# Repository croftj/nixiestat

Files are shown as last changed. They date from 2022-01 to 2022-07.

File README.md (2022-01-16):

# NixieStat Home Thermostat

NxieStat is thermostat for the home with a nixie tube display supporting
remote sensors.

All comminications to the thermostat is over wifi using the Mosquitto MQTT
message bus. The messages are in the form of json strings. 

This prject started out as an AVR based thermostat. You will see vestiges of
that in source tree. The latest code and hardware is under the **esp32**
folder. The hope is that there will be a web ui running on a Raspberry PI. The
start of this code is in the **webui** folder. It is very early code that is
mostly to prove certain components/SDKs such as **QT** & **WT** can actually be 
compiled together on the Rasberry PI.

## Hardware

### Devboard
This is currently the most tested of the two ESP32 boards. It handle an
ESP32-S2 processor. It also has a three pin connector for easily attaching a
DS18S20 temperature sensor to it. Its  primary purpose is for the temperature
sensors.

### Devboard2
This board is similar to *DevBoard* except that it is laid out for the
ESP32-WROVER-IE processor. This board has not been tested yet. It will
hopefully be the processor for use as the thermostat itself and be able to be
upgraded *over the air*

### CPU Board
This board has the relays for the furnace as wll as the interface chips for the
keyboard an the display board. It can use either *Devboard* or *Devboard2* for
it's processor board.

## Nixie Display
This board has the High voltage supply as well as the nixie tubes and neon
bulbs for the display.

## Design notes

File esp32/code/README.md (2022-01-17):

# NixieStat Thermostat Code

This code is the main source code for the NixieStat Thermostat. It is
structured to be built using the Espressif idf.py tool.

This code requires code from the github project croftj/esp_components. This 
repository should be cloned and a symbolic link named cpp_components needs to
be created in the main folder of this code pointing to the folder with code from
esp_components.

This code can be built and loaded onto the ESP32 devboard for the thermostat
using the command

   *idf.py -p /dev/ttyUSBXX build flash monitor*

Assuming that the esp32 sdk environment was previous installed and configured.

Once the unit was flashed, it will attempt to connect to wifi and the message
bus. This cannot happen until the menus are brought up by pressing <Enter> 
and setting the wifi and the MQTT parameters are configured. The menus can be traversed
using single letters. This initialization  is a bit
cumbersome because of the debug messaging, but doable. Once the parameters are
set, reset the board and it should then connect.

A value can be set by using it's name or the single letter followed without
spaces an '=' then the value. As an example *b=72<Enter>*.

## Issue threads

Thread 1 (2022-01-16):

Provide feedback for invalid configuration requests

croftj, 2022-01-16:
Currently, is a configuration is sent with an error in the value for the json format, there is no feedback on the response topic

Closed 2022-02-04.

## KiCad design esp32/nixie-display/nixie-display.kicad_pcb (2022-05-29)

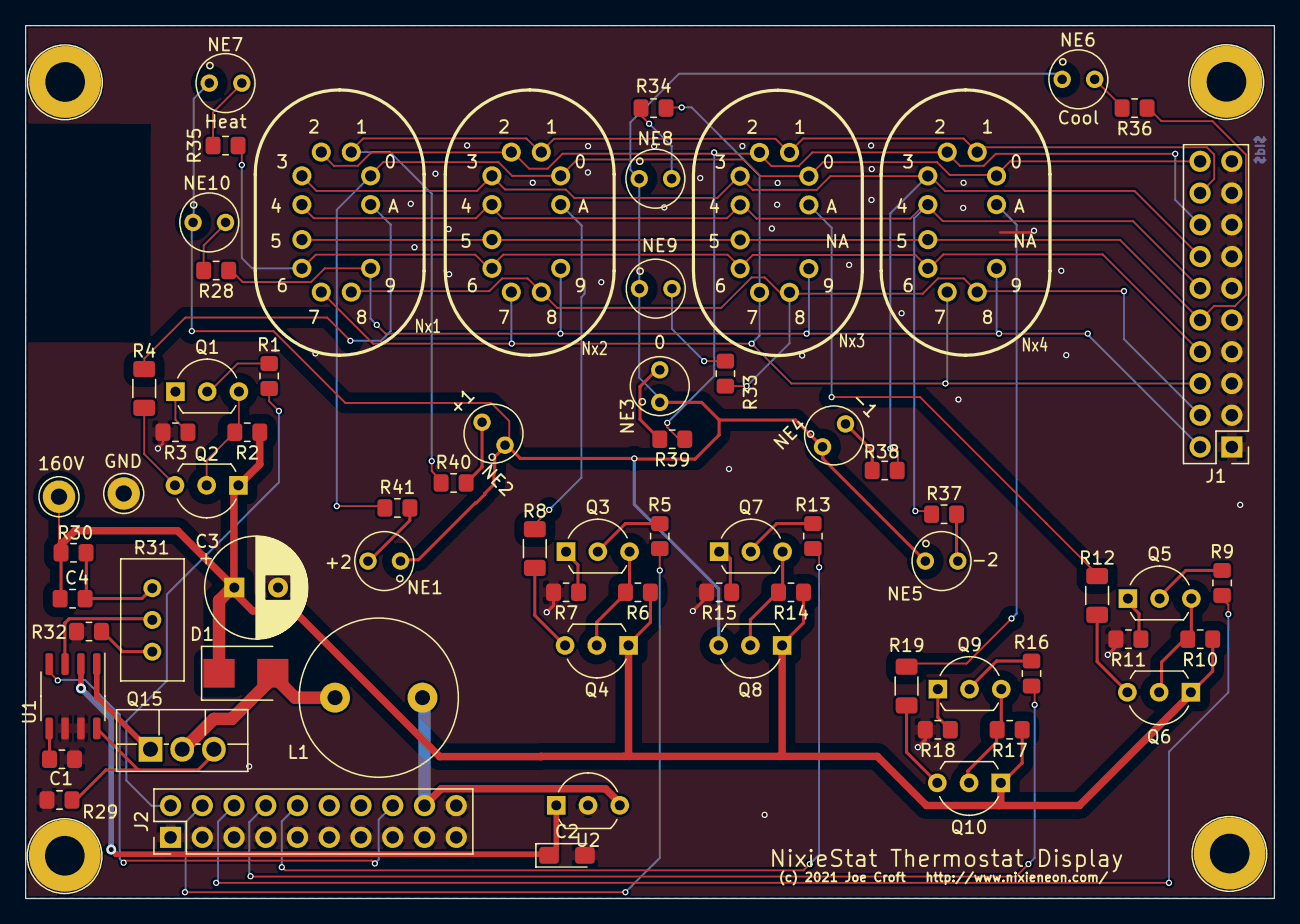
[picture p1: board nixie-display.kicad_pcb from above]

Board: 2 copper layers, 99.9 x 69.8 mm, 74 parts (0 on the bottom side), 61 nets.

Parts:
C1: 1nf; R_0805_2012Metric_Pad1.20x1.40mm_HandSolder
C2: 10uf; CP_EIA-3216-18_Kemet-A_Pad1.58x1.35mm_HandSolder
C3: 4.7uf; CP_Radial_D8.0mm_P3.50mm
C4: 2.2nf; R_0805_2012Metric_Pad1.20x1.40mm_HandSolder
D1: D_Schottky; D_SMB
J1, J2: Conn_02x10_Odd_Even; PinHeader_2x10_P2.54mm_Vertical
L1: 150uh; L_Radial_D12.5mm_P7.00mm_Fastron_09HCP
NE1: +2; NE2
NE2: +1; NE2
NE3: 0; NE2
NE4: -1; NE2
NE5: -2; NE2
NE6: Cool; NE2
NE7: Heat; NE2
NE8, NE9, NE10: Lamp_Neon; NE2
Nx1, Nx2, Nx3, Nx4: in17
Q1, Q3, Q5, Q7, Q9: MPSA42; TO-92L_Inline_Wide
Q2, Q4, Q6, Q8, Q10: MPSA92; TO-92L_Inline_Wide
Q15: IRLS640; TO-220F-3_Vertical
R1, R3, R5, R7, R9, R11, R13, R15, R16, R18: 3.3K; R_0805_2012Metric_Pad1.20x1.40mm_HandSolder
R2, R6, R10, R14, R17, R28, R33, R34, R35, R36, R37, R38, R39, R40, R41: 100K; R_0805_2012Metric_Pad1.20x1.40mm_HandSolder
R4, R8, R12, R19: 22K; R_1206_3216Metric_Pad1.30x1.75mm_HandSolder
R29: .1; R_0805_2012Metric_Pad1.20x1.40mm_HandSolder
R30: 1M; R_0805_2012Metric_Pad1.20x1.40mm_HandSolder
R31: 20K; Potentiometer_Bourns_3296W_Vertical
R32: 1.2K; R_0805_2012Metric_Pad1.20x1.40mm_HandSolder
SH1, SH2, SH3, SH4: ScrewHole; 4-40-Screw
TP1: 160V; Pin_D1.3mm_L11.0mm
TP2: GND; Pin_D1.3mm_L11.0mm
U1: MAX1771; SO-8_3.9x4.9mm_P1.27mm
U2: L78L05_TO92; TO-92_Inline_Wide

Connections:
160V: C3.1, C4.1, D1.1, Q2.1, Q4.1, Q6.1, Q8.1, Q10.1, R2.1, R6.1, R10.1, R14.1, R17.1, R30.1, TP1.1
+5V: C2.1, U1.2, U2.1
/seg0: J1.20, Nx1.0, Nx2.0, Nx3.0, Nx4.0, R41.1
/seg1: J1.18, Nx1.1, Nx2.1, Nx3.1, Nx4.1, R40.1
/seg2: J1.16, Nx1.2, Nx2.2, Nx3.2, Nx4.2, R39.1
/seg3: J1.14, Nx1.3, Nx2.3, Nx3.3, Nx4.3, R38.1
/seg4: J1.12, Nx1.4, Nx2.4, Nx3.4, Nx4.4, R37.1
/seg5: J1.10, Nx1.5, Nx2.5, Nx3.5, Nx4.5, R36.1
/seg6: J1.8, Nx1.6, Nx2.6, Nx3.6, Nx4.6, R35.1
/seg7: J1.6, Nx1.7, Nx2.7, Nx3.7, Nx4.7, R34.1
/seg8: J1.4, Nx1.8, Nx2.8, Nx3.8, Nx4.8, R33.1
/seg9: J1.2, Nx1.9, Nx2.9, Nx3.9, Nx4.9, R28.1
GNDREF: C1.2, C2.2, C3.2, J1.1, J1.3, J1.5, J1.7, J1.9, J1.11, J1.13, J1.15, J1.17, J1.19, J2.1, J2.3, J2.5, J2.7, J2.9, J2.11, J2.13, J2.15, J2.17, J2.19, J2.20, R3.2, R7.2, R11.2, R15.2, R18.2, R29.2, R32.2, SH1.1, SH2.1, SH3.1, SH4.1, TP2.1, U1.6, U1.7, U2.2
HV_DISABLE: J2.16, U1.4
unnamed: C1.1, U1.5
unnamed: C4.2, R30.2, R31.1
unnamed: D1.2, L1.2, Q15.2
unnamed: NE1.2, R41.2
unnamed: NE2.2, R40.2
unnamed: NE3.2, R39.2
unnamed: NE4.2, R38.2
unnamed: NE5.2, R37.2
unnamed: NE6.2, R36.2
unnamed: NE7.2, R35.2
unnamed: NE8.2, R34.2
unnamed: NE9.2, R33.2
unnamed: NE10.2, R28.2
unnamed: Q1.1, R3.1
unnamed: Q1.2, R1.1
unnamed: Q1.3, Q2.2, R2.2
unnamed: Q2.3, R4.2
unnamed: Q3.1, R7.1
unnamed: Q3.2, R5.1
unnamed: Q3.3, Q4.2, R6.2
unnamed: Q4.3, R8.2
unnamed: Q5.1, R11.1
unnamed: Q5.2, R9.1
unnamed: Q5.3, Q6.2, R10.2
unnamed: Q6.3, R12.2
unnamed: Q7.1, R15.1
unnamed: Q7.2, R13.1
unnamed: Q7.3, Q8.2, R14.2
unnamed: Q9.1, R18.1
unnamed: Q9.2, R16.1
unnamed: Q9.3, Q10.2, R17.2
unnamed: Q10.3, R19.2
unnamed: Q15.1, U1.1
unnamed: Q15.3, R29.1, U1.8
unnamed: R31.2, U1.3
unnamed: R31.3, R32.1
VCC: J2.18, L1.1, U2.3
dig0: Nx1.A, R4.1
dig1: Nx2.A, R8.1
dig2: Nx3.A, R12.1
dig3: Nx4.A, R19.1
dig4: NE1.1, NE2.1, NE3.1, NE4.1, NE5.1, NE6.1, NE7.1, NE8.1, NE9.1, NE10.1, Q8.3
idig0: J2.2, R1.2
idig1: J2.4, R5.2
idig2: J2.6, R9.2
idig3: J2.8, R16.2
idig4: J2.10, R13.2

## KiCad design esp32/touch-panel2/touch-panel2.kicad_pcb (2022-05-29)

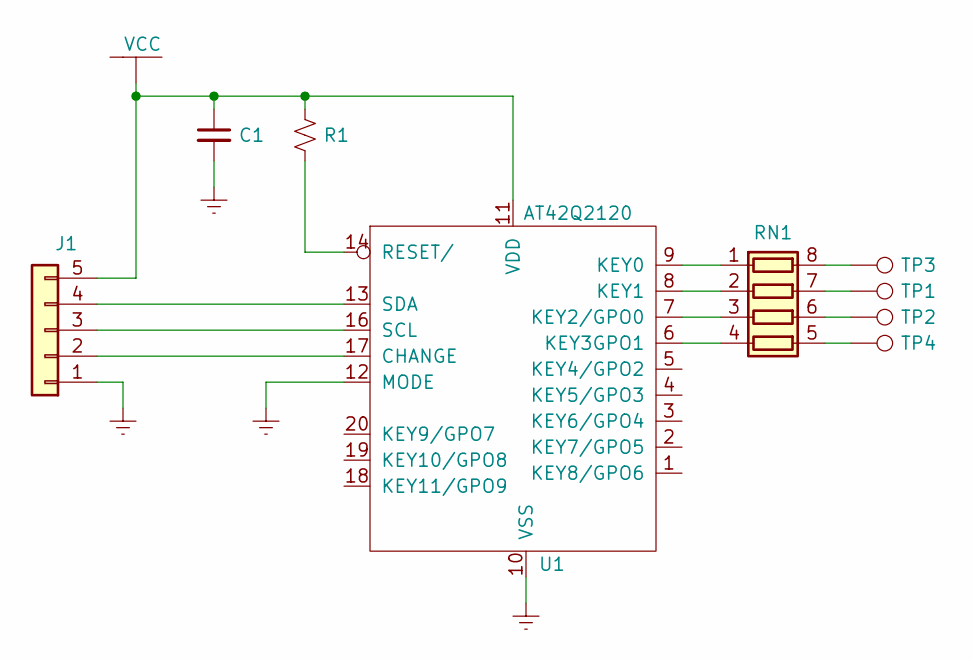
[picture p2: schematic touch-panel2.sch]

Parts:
C1: C_Small; C_0805_2012Metric_Pad1.18x1.45mm_HandSolder
J1: Conn_01x05; PinHeader_1x05_P2.54mm_Vertical
R1: R_Small_US; R_0805_2012Metric_Pad1.20x1.40mm_HandSolder
RN1: R_Pack04; R_Array_Convex_4x0603
TP1, TP2, TP3, TP4: TestPoint; Touch_Pad_Small
U1: AT42Q2120; TSSOP-20_4.4x6.5mm_P0.65mm
V1: VCC

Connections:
GNDREF: C1.2, J1.1, U1.10 (VSS), U1.12 (MODE)
unnamed: J1.2, U1.17 (CHANGE)
unnamed: J1.3, U1.16 (SCL)
unnamed: J1.4, U1.13 (SDA)
unnamed: R1.2, U1.14 (RESET/)
unnamed: RN1.1 (R1.1), U1.9 (KEY0)
unnamed: RN1.2 (R2.1), U1.8 (KEY1)
unnamed: RN1.3 (R3.1), U1.7 (KEY2/GPO0)
unnamed: RN1.4 (R4.1), U1.6 (KEY3GPO1)
unnamed: RN1.5 (R4.2), TP4.1
unnamed: RN1.6 (R3.2), TP2.1
unnamed: RN1.7 (R2.2), TP1.1
unnamed: RN1.8 (R1.2), TP3.1
VCC: C1.1, J1.5, R1.1, U1.11 (VDD), V1.1

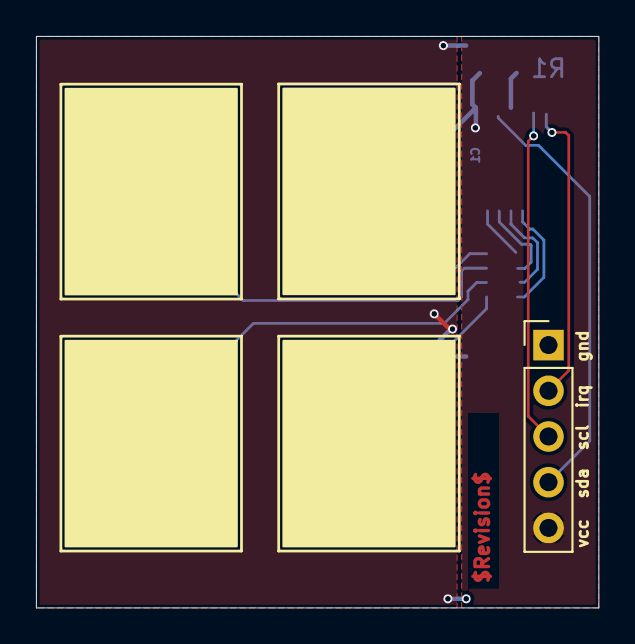
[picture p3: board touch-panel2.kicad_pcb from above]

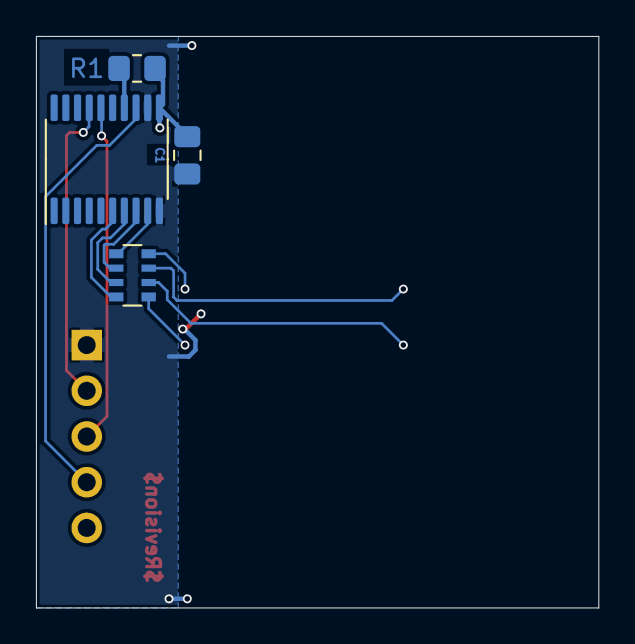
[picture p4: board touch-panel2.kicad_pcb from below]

Board: 2 copper layers, 31.2 x 31.7 mm, 9 parts (4 on the bottom side), 14 nets.

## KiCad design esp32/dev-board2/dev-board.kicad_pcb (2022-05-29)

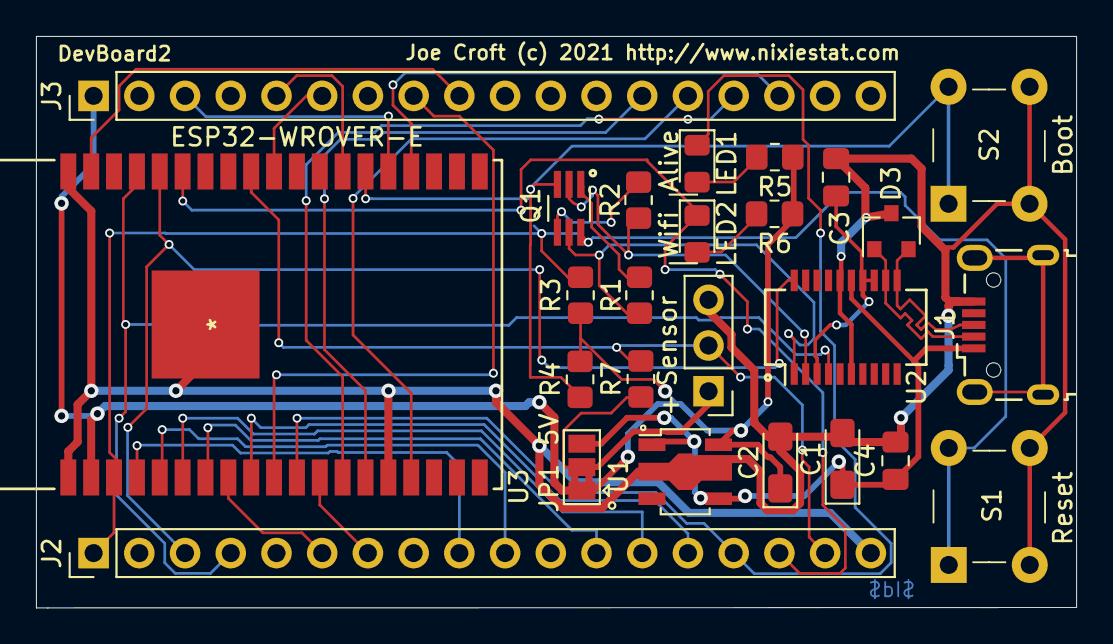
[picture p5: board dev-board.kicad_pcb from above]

Board: 2 copper layers, 57.8 x 31.8 mm, 25 parts (0 on the bottom side), 36 nets.

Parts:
C1, C2: 10uf; CP_EIA-3216-18_Kemet-A_Pad1.58x1.35mm_HandSolder
C3, C4: .1uf; C_0805_2012Metric_Pad1.18x1.45mm_HandSolder
D3: STS232; SOT-23
J1: USB_B_Micro; USB_Micro-B_Wuerth_629105150521
J2, J3: Conn_01x18_Male; PinHeader_1x18_P2.54mm_Vertical
J4: Conn_01x03_Male; PinHeader_1x03_P2.54mm_Vertical
JP1: Jumper_3_Bridged12; SolderJumper-3_P1.3mm_Bridged2Bar12_Pad1.0x1.5mm
LED1, LED2: LED; LED_0805_2012Metric_Pad1.15x1.40mm_HandSolder
Q1: MTB3904-2; SOT-363_SC-70-6_Handsoldering
R1, R2, R3, R4: 10K; R_0805_2012Metric_Pad1.20x1.40mm_HandSolder
R5, R6: 75; R_0805_2012Metric_Pad1.20x1.40mm_HandSolder
R7: 2.3K; R_0805_2012Metric_Pad1.20x1.40mm_HandSolder
S1, S2: B3F-1052; Switch_Tactile_THT_B3F-1xxx
U1: AP7361C-33Y5-13; SOT-89-5
U2: FT231XS; SSOP-20_3.9x8.7mm_P0.635mm
U3: ESP32-WROVER-E; ESP32-WROVER-EM213EH2864PH3Q0

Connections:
+3.3V: C2.1, J3.1, JP1.1, R3.2, R4.2, R5.1, R6.1, U1.5, U3.2
+5V: C1.1, C4.1, J1.1, JP1.3, U1.1, U1.4, U2.15
/USB_N: D3.1, J1.2, U2.12
/USB_P: D3.2, J1.3, U2.11
GNDREF: C1.2, C2.2, C3.2, C4.2, D3.3, J1.5, J2.18, J4.3, S1.3, S1.4, S2.3, S2.4, U1.2, U2.6, U2.16, U3.1, U3.15, U3.38, U3.39
IO-00: Q1.3, R4.1, S2.1, S2.2, U3.25
IO-02: J3.3, U3.24
IO-04: J3.5, U3.26
IO-05: J3.6, U3.29
IO-12: J3.13, U3.14
IO-13: J3.14, U3.16
IO-14: J3.15, U3.13
IO-15: J3.16, U3.23
IO-18: J2.17, J4.2, R7.2, U3.30
IO-21: J2.16, LED2.1, U3.33
IO-23: J3.9, U3.37
IO-25: J3.8, U3.10
IO-26: J2.15, LED1.1, U3.11
IO-27: J2.7, U3.12
IO-32: J2.6, U3.8
IO-33: J2.14, U3.9
IO-34: J2.13, U3.6
IO-35: J2.12, U3.7
unnamed: C3.1, U2.3, U2.13, U2.14
unnamed: J4.1, JP1.2, R7.1
unnamed: LED1.2, R5.2
unnamed: LED2.2, R6.2
unnamed: Q1.1, R1.2
unnamed: Q1.2, R2.1, U2.2
unnamed: Q1.4, R2.2
unnamed: Q1.5, R1.1, U2.1
RESET: J2.1, Q1.6, R3.1, S1.1, S1.2, U3.3
RXD0: J2.3, U2.20, U3.34
SENSOR_VN: J2.10, U3.5
SENSOR_VP: J2.9, U3.4
TXD0: J2.4, U2.4, U3.35

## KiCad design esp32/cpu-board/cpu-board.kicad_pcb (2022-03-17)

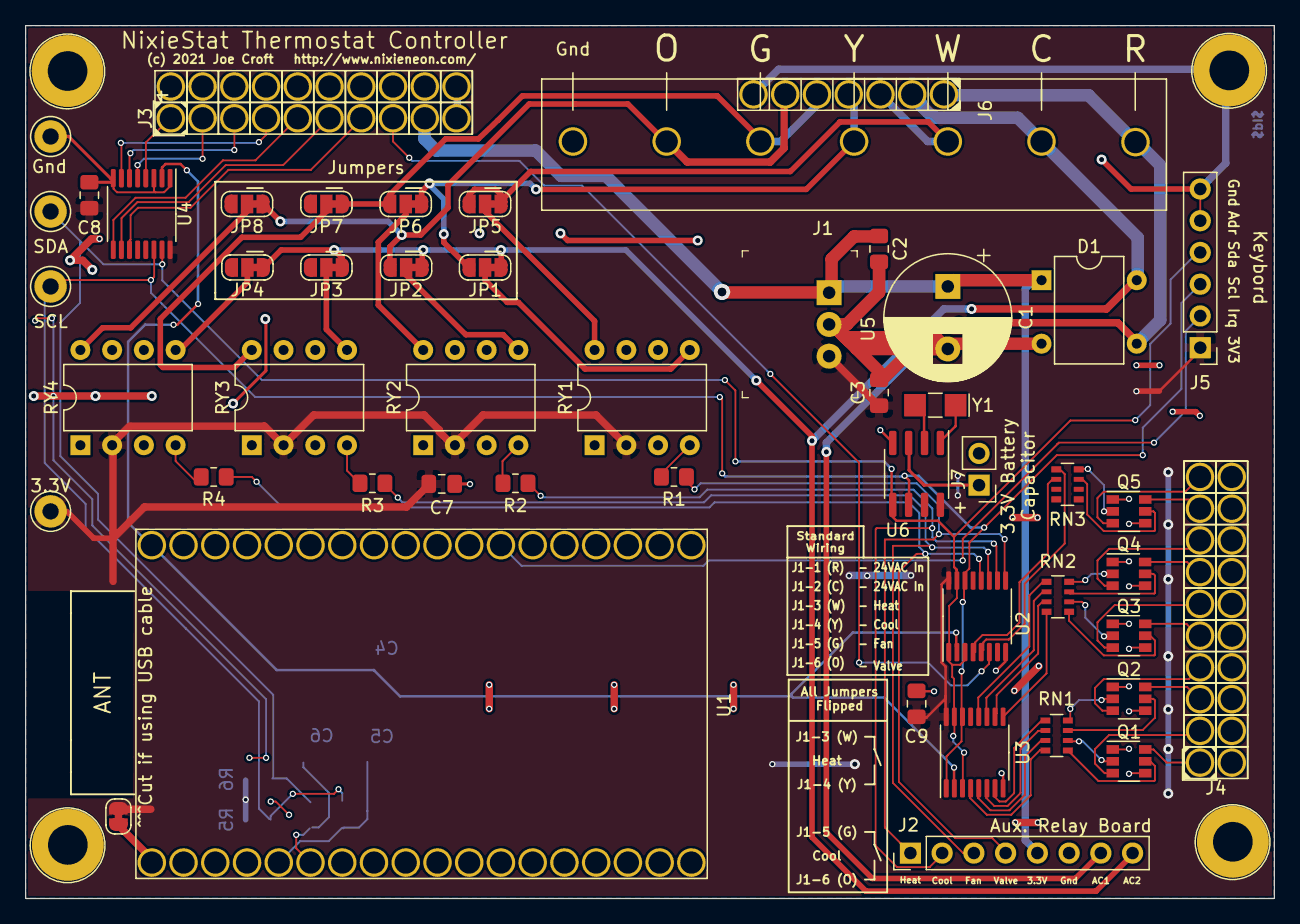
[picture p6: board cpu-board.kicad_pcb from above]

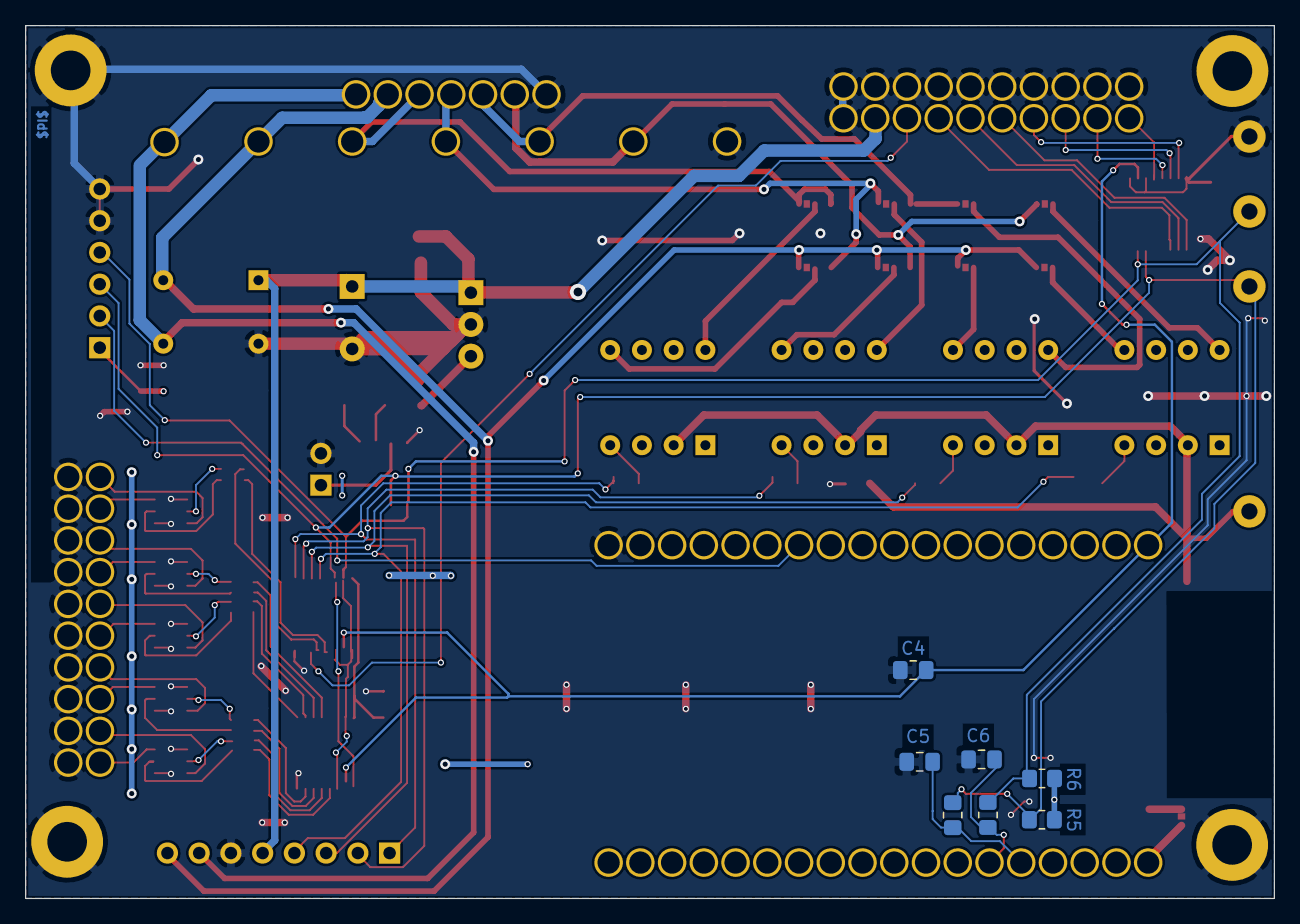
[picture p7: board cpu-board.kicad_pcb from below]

Board: 2 copper layers, 99.9 x 69.8 mm, 61 parts (7 on the bottom side), 73 nets.

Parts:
C1: 100uf 35V; CP_Radial_D10.0mm_P5.00mm
C2, C3: 10uf 35V; C_0805_2012Metric_Pad1.18x1.45mm_HandSolder
C4, C5, C6, C7, C8, C9: .1uf; C_0805_2012Metric_Pad1.18x1.45mm_HandSolder
D1: DF01M; Diode_Bridge_DIP-4_W7.62mm_P5.08mm
J1: Conn_01x07; conn-phx-1703090
J2: Conn_01x08; PinHeader_1x08_P2.54mm_Vertical
J3: Conn_02x10_Odd_Even; pcb_jack-2x10
J4: Conn_02x10_Odd_Even; pcb_jack-2x10-mirror
J5: Conn_01x06; PinHeader_1x06_P2.54mm_Vertical
J6: Conn_01x07; Mill-Max-295x7
J7: Battery; PinHeader_1x02_P2.54mm_Vertical
JP1, JP2, JP3, JP4, JP5, JP6, JP7, JP8: SolderJumper_3_Bridged12; SolderJumper-3_P1.3mm_Bridged12_RoundedPad1.0x1.5mm_NumberL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
JP9: Jumper_2_Bridged; SolderJumper-2_P1.3mm_Bridged_RoundedPad1.0x1.5mm
Q1, Q2, Q3, Q4, Q5: PMBTA42DS,125; SuperSOT-6
R1, R2, R3, R4: R_US; R_0805_2012Metric_Pad1.20x1.40mm_HandSolder
R5, R6: 100K; R_0805_2012Metric_Pad1.20x1.40mm_HandSolder
R7, R8: 0 Ohm; R_0805_2012Metric_Pad1.20x1.40mm_HandSolder
RN1, RN2, RN3: R_Pack04; R_Array_Convex_4x0603
RY1, RY2, RY3, RY4: AQH3213; DIP-8_W7.62mm
SH1, SH2, SH3, SH4: ScrewHole; 4-40-Screw
TP1: Gnd; Pin_D1.3mm_L11.0mm
TP2: SCL; Pin_D1.3mm_L11.0mm
TP3: SDA; Pin_D1.3mm_L11.0mm
TP4: 3.3V; Pin_D1.3mm_L11.0mm
U1: ESP32-DevBoard2; ESP32-DevKit-pcb-recepticals
U2, U3, U4: MAX7320; TSSOP-16_4.4x5mm_P0.65mm
U5: V7803-1000; 3-SIP_Module_V7805-1000
U6: PT7C4339; SOIC-8_3.9x4.9mm_P1.27mm
Y1: 32.788Khz; Crystal_SMD_G8-2Pin_3.2x1.5mm_HandSoldering

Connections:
+3.3V: C3.1, C7.1, C8.1, C9.1, J5.1, JP9.1, R5.1, R6.1, RY1.2, RY2.2, RY3.2, RY4.2, TP4.1, U2.16, U3.16, U4.16, U5.3, U6.8
AC1: D1.3, J1.1, J2.7, J6.1
AC2: D1.4, J1.2, J2.8, J6.2, JP1.1, JP2.1, JP3.1, JP4.1
COOL: J2.2, R2.2, U2.10
FAN: J2.3, R3.2, U2.11
GNDREF: C1.2, C2.2, C3.2, C4.2, C5.2, C6.2, C7.2, C8.2, C9.2, D1.2, J1.7, J2.6, J3.2, J3.4, J3.6, J3.8, J3.10, J3.12, J3.14, J3.16, J3.18, J3.19, J3.20, J4.2, J4.4, J4.6, J4.8, J4.10, J4.12, J4.14, J4.16, J4.18, J4.20, J5.5, J5.6, J6.7, J7.2, Q1.1, Q1.4, Q2.1, Q2.4, Q3.1, Q3.4, Q4.1, Q4.4, Q5.1, Q5.4, SH1.1, SH2.1, SH3.1, SH4.1, TP1.1, U1.19, U2.8, U3.8, U4.1, U4.3, U4.8, U5.2, U6.4
HEAT: J2.1, R1.2, U2.9
I2C_SCL: J5.3, R5.2, R7.1, TP2.1, U2.14, U3.1, U3.14, U4.14, U6.6
I2C_SDA: J5.4, R6.2, R8.1, TP3.1, U2.1, U2.3, U2.15, U3.3, U3.15, U4.15, U6.5
KEY_IRQ: J5.2, U1.25
unnamed: C5.1, R7.2, U1.5
unnamed: C6.1, R8.2, U1.6
unnamed: J1.3, J6.3, JP5.1, JP5.3
unnamed: J1.4, J6.4, JP1.3, JP6.1
unnamed: J1.5, J6.5, JP6.3, JP7.1
unnamed: J1.6, J6.6, JP2.3, JP8.1
unnamed: J3.1, U4.4
unnamed: J3.3, U4.5
unnamed: J3.5, U4.6
unnamed: J3.7, U4.7
unnamed: J3.9, U4.9
unnamed: J3.11, U4.10
unnamed: J3.13, U4.11
unnamed: J7.1, U6.3
unnamed: JP1.2, RY1.5
unnamed: JP2.2, RY2.5
unnamed: JP3.2, RY3.5
unnamed: JP4.2, RY4.5
unnamed: JP5.2, RY1.8
unnamed: JP6.2, RY2.8
unnamed: JP7.2, RY3.8
unnamed: JP8.2, RY4.8
unnamed: JP9.2, U1.1
unnamed: R1.1, RY1.4
unnamed: R2.1, RY2.4
unnamed: R3.1, RY3.4
unnamed: R4.1, RY4.4
unnamed: RN1.5, U3.7
unnamed: RN1.6, U3.6
unnamed: RN1.7, U3.5
unnamed: RN1.8, U3.4
unnamed: RN2.5, U3.12
unnamed: RN2.6, U3.11
unnamed: RN2.7, U3.10
unnamed: RN2.8, U3.9
unnamed: RN3.5, U2.5
unnamed: RN3.6, U2.4
unnamed: U6.1, Y1.1
unnamed: U6.2, Y1.2
RESET: C4.1, U1.36, U2.2, U3.2, U4.2
SEG1: Q1.5, RN1.1
SEG2: Q1.2, RN1.2
SEG3: Q2.5, RN1.3
SEG4: Q2.2, RN1.4
SEG5: Q3.5, RN2.1
SEG6: Q3.2, RN2.2
SEG7: Q4.5, RN2.3
SEG8: Q4.2, RN2.4
SEG9: Q5.5, RN3.3
SEG10: Q5.2, RN3.4
SEG_D_1: J4.1, Q1.6
SEG_D_2: J4.3, Q1.3
SEG_D_3: J4.5, Q2.6
SEG_D_4: J4.7, Q2.3
SEG_D_5: J4.9, Q3.6
SEG_D_6: J4.11, Q3.3
SEG_D_7: J4.13, Q4.6
SEG_D_8: J4.15, Q4.3
SEG_D_9: J4.17, Q5.6
SEG_D_10: J4.19, Q5.3
VALVE: J2.4, R4.2, U2.12
VCC: C1.1, C2.1, D1.1, J2.5, J3.17, U5.1
~HV_EN~: J3.15, U2.6

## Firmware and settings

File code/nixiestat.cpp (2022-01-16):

//#define  MINIMAL
//#define  NO_EXEC
//#define  NO_LOG
//#define  NO_MENU_EXEC
//#define  DISPLAY_OFF
// #define  DBG
#define  POLLING  1
#define REGCHANNEL

# include <avr/pgmspace.h>
# include <ctype.h>
# include <math.h>
# include <stdio.h>
# include <stdlib.h>

# include "EEPROM.h"
# include "IOPort.h"

# include "datetime.h"
# include "esquare.h"
# include "menu.h"

#ifndef MINIMAL 
# include "display.h"
# include "PID.h"
# include "SystemLogger.h"
# include "TempCycle.h"
# include "TempSensors.h"
# include "thermostat.h"
# include "WProgram.h"
# include "Wire.h"
# include "ds1307.h"
# include "mpr121.h"
# include "switches.h"
# include "ui.h"
#endif

#define  LOG_SIZE                (15 * 1024)
//#define  LOG_SIZE                (100)
#define  READ_TEMPERATURE_TIME   15
#define  READ_SENSOR_TIME        2
#define  DISP_TEMPERATURE_TIME   10
#define  LOG_TEMPERATURE_TIME    (30 * 60)
//#define  LOG_TEMPERATURE_TIME    (30)
#define  RESERVED_STACK          8192

enum
{
   TIME_LAPSE_MASK  = 0xf000,
   TIME_LAPSE_SHIFT = 12,
   CHANNEL_MASK     = 0x0c00,
   CHANNEL_SHIFT    = 10,
   TEMPERATURE_MASK = 0x03ff,
   TEMPERATURE_SIGN = 0x0200,
   LOG_LENGTH       = 12 * 1024,
   TEMP_OFFSET      = 40
};

#ifdef DBG
uint8_t dbg = 4;
#else
uint8_t dbg = 0;
#endif

#ifndef MINIMAL 
#ifndef NO_LOG
SystemLogger syslog;
#endif

TempSensors sensors;
PID pid(5, 2, 10);

MPR121 mpr121;
#endif

bool tempIsReady = 0;
uint8_t tempCounter = 12;

char p_buf[128];
char ibuf[32];
bool needPrompt = 0;
bool *pid_debug = NULL;

MenuEntry *main_menu;

const char invalidEntry_str[] PROGMEM = "\nInvalid Entry!";

# ifdef REGCHANNEL
#ifndef NO_LOG
const char OUTSIDE_SENSOR_AVG_LOG[] PROGMEM  = "OutAvg";
const char OUTSIDE_SENSOR_MIN_LOG[] PROGMEM  = "OutMin";
const char OUTSIDE_SENSOR_MAX_LOG[] PROGMEM  = "OutMax";

const char INSIDE_SENSOR_AVG_LOG[] PROGMEM   = "InAvg";
const char INSIDE_SENSOR_MIN_LOG[] PROGMEM   = "InMin";
const char INSIDE_SENSOR_MAX_LOG[] PROGMEM   = "InMax";

const char CYCLE_SENSOR_TGT_LOG[] PROGMEM    = "CycTgt";
const char CYCLE_SENSOR_AVG_LOG[] PROGMEM    = "CycAvg";
const char CYCLE_SENSOR_MIN_LOG[] PROGMEM    = "CycMin";
const char CYCLE_SENSOR_MAX_LOG[] PROGMEM    = "CycMax";
const char CYCLE_STATE_LOG[]      PROGMEM    = "CycState";

const char TARGET_TEMP_LOG[] PROGMEM         = "TgtTemp";
const char PID_ITERM_LOG[] PROGMEM           = "PIDITerm";
# endif
# endif
/**********************************************************************/
/*   Menu Strings                                                     */
/**********************************************************************/
const char MENU_MAINMENU_STR[] PROGMEM = "Main Menu";

const char MENU_MM11_STR[] PROGMEM = "Cycle State";
const char MENU_MM10_STR[] PROGMEM = "Cycle Temp.";
const char MENU_MM9_STR[]  PROGMEM = "Outside Temp.";
const char MENU_MM8_STR[]  PROGMEM = "Inside Temp.";
const char MENU_MM7_STR[]  PROGMEM = "Dump full Log";
const char MENU_MM6_STR[]  PROGMEM = "Dump Log";
const char MENU_MM5_STR[]  PROGMEM = "Save Settings";
const char MENU_MM4_STR[]  PROGMEM = "Date";
const char MENU_MM3_STR[]  PROGMEM = "Time";
const char MENU_MM2_STR[]  PROGMEM = "Mode";
const char MENU_MM1_STR[]  PROGMEM = "Set Temperature";

const char MENU_SYSMENU_STR[]    PROGMEM = "System";
const char MENU_SY7_STR[]        PROGMEM = "PID Debug";
const char MENU_SY6_STR[]        PROGMEM = "Reset Count";
const char MENU_SY5_STR[]        PROGMEM = "Clear Log";
const char MENU_SY4_STR[]        PROGMEM = "Show Esquare";
const char MENU_SY3_STR[]        PROGMEM = "Show menu Map";
const char MENU_SY2_STR[]        PROGMEM = "Debug Level";
const char MENU_SY1_STR[]        PROGMEM = "Log Interval";

const char MENU_KYPMENU_STR[]    PROGMEM = "Key Pad";
const char MENU_KP1_STR[]        PROGMEM = "Touch Thresh";
const char MENU_KP2_STR[]        PROGMEM = "Release Thresh";
const char MENU_KP3_STR[]        PROGMEM = "Initialize";


const char MENU_HYSTMENU_STR[]   PROGMEM = "Hysteresis";
const char MENU_HM2_STR[]        PROGMEM = "Cooling";
const char MENU_HM1_STR[]        PROGMEM = "Heating";

const char MENU_SENSORSMENU_STR[]   PROGMEM = "Sensors";
const char MENU_SM4_STR[]           PROGMEM = "Status";
const char MENU_SM3_STR[]           PROGMEM = "Discover";
const char MENU_SM2_STR[]           PROGMEM = "Exterior";
const char MENU_SM1_STR[]           PROGMEM = "Interior";

const char MENU_THERMOSTATMENU_STR[]   PROGMEM = "Thermostat";
const char MENU_TMS02_STR[]            PROGMEM = "Vacation";
const char MENU_TMS01_STR[]            PROGMEM = "Max Cycle Time";

const char MENU_HEATINGMENU_STR[] PROGMEM = "Heating";

const char MENU_THM12_STR[] PROGMEM = "Min Cycle Time";
const char MENU_THM11_STR[] PROGMEM = "Time4";
const char MENU_THM10_STR[] PROGMEM = "Temp4";

const char MENU_THM08_STR[] PROGMEM = "Time3";
const char MENU_THM07_STR[] PROGMEM = "Temp3";

const char MENU_THM05_STR[] PROGMEM = "Time2";
const char MENU_THM04_STR[] PROGMEM = "Temp2";

const char MENU_THM02_STR[] PROGMEM = "Time1";
const char MENU_THM01_STR[] PROGMEM = "Temp1";

const char MENU_HEATINGPIDMENU_STR[]         PROGMEM = "PID Settings";
const char MENU_HEATINGADVANCEDPIDMENU_STR[] PROGMEM = "Advanced Settings";

const char MENU_HPM4_STR[] PROGMEM = "Cycle Maximum";
const char MENU_HPM3_STR[] PROGMEM = "Cycle Minimum";
const char MENU_HPM2_STR[] PROGMEM = "Cycle Hysteresis";
const char MENU_HPM1_STR[] PROGMEM = "Enabled";

const char MENU_HAPM6_STR[] PROGMEM = "Kp";
const char MENU_HAPM5_STR[] PROGMEM = "Ki";
const char MENU_HAPM4_STR[] PROGMEM = "Kd";
const char MENU_HAPM3_STR[] PROGMEM = "Curve";
const char MENU_HAPM2_STR[] PROGMEM = "Adjust";
const char MENU_HAPM1_STR[] PROGMEM = "Sensor";

const char MENU_COOLINGMENU_STR[] PROGMEM = "Cooling";

/**********************************************************************/
/*   This function displays the time in an almost pleasant way.       */
/**********************************************************************/
char *formatLogEntry(char *buf, time_t thisTime, uint8_t channel, float temp)
{
#ifndef MINIMAL
//   sprintf(buf,strcpy_P(p_buf, PSTR("%ld,%s,%d,%s,%3.2f")), thisTime, DateTime::formatTime(thisTime), channel, thermostat.formatTempSensorAddr(channel), (double)temp);
#else
   *buf = '\0';
#endif
   return(buf);
}

/**********************************************************************/
/*   Function to update the settings in the settings area. This will  */
/*   also  send  required  settings  out to the various objects that  */
/*   depend on the settings                                           */
/**********************************************************************/
int updateThermostatSettings(ESquareSpace_t *settings)
{
#ifndef MINIMAL
   Serial << strcpy_P(p_buf, PSTR("Updating thermostat settings...")) << endl;
   temp_cycle.setSensor(settings->targetSensor);
   temp_cycle.setMode(settings->currentMode);
   if ( settings->currentMode == Settings::Cool ) 
   {
      temp_cycle.setAbsMinimum(settings->coolCycleMinimum);
      temp_cycle.setHysterisis(settings->coolHyst);
      if ( settings->coolPidEnabled == true ) 
      {
         temp_cycle.setSensor(settings->coolCycleSensor);
         temp_cycle.setHysterisis(settings->coolCycleHyst);
         pid.SetControllerDirection(REVERSE);
      }
      settings->cycleSensor   = settings->coolCycleSensor;
      settings->cycleMaximum  = settings->coolCycleMaximum;
      settings->cycleMinimum  = settings->coolCycleMinimum;
      settings->cycleTime     = settings->coolMinCycleTime;
      settings->outsideCurve  = settings->coolOutsideCurve;
      settings->outsideAdj    = settings->coolOutsideAdj;
      settings->Ki            = settings->coolKi;
      settings->Kp            = settings->coolKp;
      settings->Kd            = settings->coolKd;
      settings->pidEnabled    = settings->coolPidEnabled;
   }
   else 
   {
      temp_cycle.setAbsMaximum(settings->heatCycleMaximum);
      temp_cycle.setHysterisis(settings->heatHyst);
      if ( settings->heatPidEnabled == true ) 
      {
         temp_cycle.setSensor(settings->heatCycleSensor);
         temp_cycle.setHysterisis(settings->heatCycleHyst);
         pid.SetControllerDirection(DIRECT);
      }
      settings->cycleSensor   = settings->heatCycleSensor;
      settings->cycleMaximum  = settings->heatCycleMaximum;
      settings->cycleMinimum  = settings->heatCycleMinimum;
      settings->cycleTime     = settings->heatMinCycleTime;
      settings->outsideCurve  = settings->heatOutsideCurve;
      settings->outsideAdj    = settings->heatOutsideAdj;
      settings->Ki            = settings->heatKi;
      settings->Kp            = settings->heatKp;
      settings->Kd            = settings->heatKd;
      settings->pidEnabled    = settings->heatPidEnabled;
   }
   temp_cycle.setTemp(settings->cycleTemp);
   Serial << __FUNCTION__ << strcpy_P(p_buf, PSTR("Setting minimum cycle time ")) << (unsigned int)settings->cycleTime << endl;
   temp_cycle.setCycleTime(settings->cycleTime);
   Serial << __FUNCTION__ << strcpy_P(p_buf, PSTR("Setting maximum cycle time ")) << (unsigned int)settings->maxCycleTime << endl;
   temp_cycle.setMaxCycleTime(settings->maxCycleTime);

   pid.SetSampleTime(READ_TEMPERATURE_TIME * 1000);
   pid.SetOutputLimits(-15.0, 105.0);
   pid.SetTarget(settings->targetTemp);
   pid.SetTunings(settings->Kp, settings->Ki, settings->Kd);
   if ( settings->currentMode == Settings::Heat ) 
   {
      Serial << __FUNCTION__ << strcpy_P(p_buf, PSTR("Setting pid direct")) << endl;
      pid.SetControllerDirection(DIRECT);
   }
   else 
   {
      Serial << __FUNCTION__ << strcpy_P(p_buf, PSTR("Setting pid reverse")) << endl;
      pid.SetControllerDirection(REVERSE);
   }
#endif
}

bool discoverSensors()
{
   Serial << strcpy_P(p_buf, PSTR("Discovering sensors...")) << endl;
   sensors.discover();
   Serial << strcpy_P(p_buf, PSTR("Sensors found")) << endl;
   sensors.dumpSensors();
   return(false);
}

bool dump_esquare()
{
   eeprom.DisplaySettings();
   return(false);
}

bool show_menu_map()
{
   main_menu->PrintChildren();
}

/**********************************************************************/
/*   Menu  helper  function  which writes the eeprom data out to the  */
/*   eeprom                                                           */
/**********************************************************************/
bool write_eeprom()
{
   eeprom.write();
   return(false);
}

void showCycleStatus()
{
   uint16_t cycle_time = temp_cycle.getMinimumCycleTime();
   int16_t time_remaining = cycle_time - temp_cycle.getCurrentCycleTime();
   if ( time_remaining < 0 ) 
   {
      time_remaining = 0;
   }
   Serial << (temp_cycle.getLastCall() ? strcpy_P(p_buf, PSTR("on")) : strcpy_P(p_buf, PSTR("off")));
   Serial << strcpy_P(p_buf, PSTR(": "));
   if ( time_remaining > 0 ) 
   {
      Serial << time_remaining << strcpy_P(p_buf, PSTR(" of "));
      Serial << cycle_time << strcpy_P(p_buf, PSTR(" secs remaining"));
   }
   else 
   {
      Serial << strcpy_P(p_buf, PSTR("for "));
      Serial << temp_cycle.getCurrentCycleTime() << strcpy_P(p_buf, PSTR(" secs"));
   }
}

void showCycleTemp()
{
   ESquareSpace_t *settings = eeprom.settings();
   if ( settings->pidEnabled ) 
   {
      if ( settings->currentMode == Settings::Heat ) 
      {
         Serial << sensors.read(settings->heatCycleSensor, TempSensors::CURRENT);
      }
      else 
      {
         Serial << sensors.read(settings->coolCycleSensor, TempSensors::CURRENT);
      }
   }
   else 
   {
      Serial << "N/A";
   }
}

void showOutsideTemp()
{
   ESquareSpace_t *settings = eeprom.settings();
   Serial << sensors.read(settings->outsideSensor, TempSensors::CURRENT);
}

void showInsideTemp()
{
   ESquareSpace_t *settings = eeprom.settings();
   Serial << sensors.read(settings->targetSensor, TempSensors::CURRENT);
}

bool voidAction(const char *buf)
{
   return(false);
}

/**********************************************************************/
/*   Menu  helper  program  the shows the current time all formatted  */
/*   pretty.                                                          */
/**********************************************************************/
void showTime()
{
   time_t now = currentDate.now();
   Serial << DateTime::formatTime(now);
}

/**********************************************************************/
/*   Menu  helper  program  the shows the current date all formatted  */
/*   pretty.                                                          */
/**********************************************************************/
void showDate()
{
   time_t now = currentDate.now();
   Serial << DateTime::formatDate(now);
}
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
int main()
{
   uint32_t   lastStartTime = 0;
   uint32_t   lastTime = 0;

   float temp = 32.0;
   int x = 0;
   uint16_t lcnt = 0;

   pid_debug = pid.GetDebugPointer();

   /***********************************************/
   /*   Initialize  the  serial port and show we  */
   /*   had a reset!                              */
   /***********************************************/
   init();
   Serial.begin(115200); //hello
   Serial << endl;
   Serial << endl;
   Serial << strcpy_P(p_buf, PSTR("/************                                    ************/")) << endl;
   Serial << strcpy_P(p_buf, PSTR("/************           R  E  S  E  T            ************/")) << endl;
   Serial << strcpy_P(p_buf, PSTR("/************                                    ************/")) << endl;

   /***********************************************/
   /*   Get the current esquare settings          */
   /***********************************************/
   Serial << strcpy_P(p_buf, PSTR("Fetching settings...")) << endl;

   // Read the ESquare
   ESquareSpace_t *settings = eeprom.settings();
//   if (dbg) Serial << __PRETTY_FUNCTION__ << strcpy_P(p_buf, PSTR("Reading eeprom")) << endl;
   eeprom.read();

   currentDate.getTime();

   /***********************************************/
   /*   If  this  is our very first time to wake  */
   /*   up  after being flashed, set some og the  */
   /*   settings to some sensible values          */
   /***********************************************/
   Serial << strcpy_P(p_buf, PSTR("coolCycleSensor = 0x")) << itoa((uint8_t)settings->coolCycleSensor, ibuf, 16) << endl;

#ifdef PID_DBG
      *pid_debug = true;
#else
      *pid_debug = false;
#endif

   if ( (uint8_t)settings->coolCycleSensor == 0xff ) 
   {
      Serial << strcpy_P(p_buf, PSTR("EEProm empty, creating initial settings:")) << endl;
      settings->heatPidEnabled   = true;
      settings->heatCycleMinimum = 60.0;
      settings->heatCycleMaximum = 140.0;
      settings->heatCycleHyst    = 15.0;
      settings->heatHyst         = 2.0;

      settings->coolPidEnabled   = false;
      settings->coolCycleMinimum = 30.0;
      settings->coolCycleMaximum = 90.0;
      settings->coolCycleHyst    = 5.0;
      settings->coolHyst         = 2.0;

      settings->heatCycleSensor  = 3;
      settings->coolCycleSensor  = 6;
      settings->targetSensor     = 6;
      settings->outsideSensor    = 2;

      settings->heatMinCycleTime = 10;
      settings->coolMinCycleTime = 7;
      settings->maxCycleTime     = 40;

      settings->heatTemps[0]     = 69.0;
      settings->heatTemps[1]     = 72.0;
      settings->heatTemps[2]     = 68.0;
      settings->heatTemps[3]     = 72.0;
      settings->heatTemps[4]     = 68.0;
      settings->heatTimes[1]     = 240;
      settings->heatTimes[2]     = 600;
      settings->heatTimes[3]     = 960;
      settings->heatTimes[4]     = 1260;
      settings->outsideTemp      = 25.0;
      settings->heatOutsideAdj   = 50.0;
      settings->coolOutsideAdj   = 0.0;
      settings->heatOutsideCurve = 0;
      settings->coolOutsideCurve = 0;
      settings->heatKp           = 50.0;
      settings->heatKi           = 0.05;
      settings->heatKd           = 55.0;
      settings->coolKp           = 50.0;
      settings->coolKi           = 0.05;
      settings->coolKd           = 55.0;

      settings->vacationTemp     = 60.0;

      settings->currentMode      = Settings::Heat;
      settings->logTime          = LOG_TEMPERATURE_TIME;
      settings->vacationMode     = false;
      settings->autoMode         = false;
      settings->resetCounter     = -1;

      settings->keyTouch         = 0x3f;
      settings->keyRelease       = 0x2a;
   }
   else 
   {
      settings->resetCounter++;
   }
   eeprom.write();

   /***********************************************/
   /*   Create the Menus                          */
   /***********************************************/
   Serial << strcpy_P(p_buf, PSTR("Building menus...")) << endl;

   MenuEntry mainMenu(MENU_MAINMENU_STR, MenuEntry::MainMenu, NULL);

   MenuEntry mm11(MENU_MM11_STR, MenuEntry::CustomIO, voidAction, showCycleStatus, &mainMenu);
   MenuEntry mm10(MENU_MM10_STR, MenuEntry::CustomIO, voidAction, showCycleTemp, &mainMenu);
   MenuEntry  mm9(MENU_MM9_STR,  MenuEntry::CustomIO, voidAction, showOutsideTemp, &mainMenu);
   MenuEntry  mm8(MENU_MM8_STR,  MenuEntry::CustomIO, voidAction, showInsideTemp, &mainMenu);
   MenuEntry  mm7(MENU_MM7_STR,  MenuEntry::Action, dump_full_log, &mainMenu);
   MenuEntry  mm6(MENU_MM6_STR,  MenuEntry::Action, dump_log, &mainMenu);
   MenuEntry  mm5(MENU_MM5_STR,  MenuEntry::Action, write_eeprom, &mainMenu);
   MenuEntry  mm4(MENU_MM4_STR,  MenuEntry::CustomIO, parseDate, showDate, &mainMenu);
   MenuEntry  mm3(MENU_MM3_STR,  MenuEntry::CustomIO, parseTime, showTime, &mainMenu);
   MenuEntry  mm2(MENU_MM2_STR,  MenuEntry::CustomIO, parse_current_mode, show_current_mode, &mainMenu);
   MenuEntry  mm1(MENU_MM1_STR,  MenuEntry::CustomIO, ParseTargetTemp, ShowTargetTemp, &mainMenu);

   MenuEntry systemMenu(MENU_SYSMENU_STR, MenuEntry::SubMenu, &mainMenu);
   MenuEntry sy7(MENU_SY6_STR, MenuEntry::Int32, (unsigned int*)&settings->resetCounter, &systemMenu);
   MenuEntry sy6(MENU_SY5_STR, MenuEntry::Action, clear_log, &systemMenu);
   MenuEntry sy5(MENU_SY4_STR, MenuEntry::Action, dump_esquare, &systemMenu);
   MenuEntry sy4(MENU_SY3_STR, MenuEntry::Action, show_menu_map, &systemMenu);
   MenuEntry sy3(MENU_SY7_STR, MenuEntry::YesNo, (unsigned int*)pid_debug, &systemMenu);
   MenuEntry sy2(MENU_SY2_STR, MenuEntry::Int8, (unsigned int*)&dbg, &systemMenu);
   MenuEntry sy1(MENU_SY1_STR, MenuEntry::Int32, (unsigned int*)&settings->logTime, &systemMenu);

   MenuEntry keypadMenu(MENU_KYPMENU_STR, MenuEntry::SubMenu, &systemMenu);
   MenuEntry ky3(MENU_KP3_STR, MenuEntry::Action, initialize_keypad, &keypadMenu);
   MenuEntry ky2(MENU_KP2_STR, MenuEntry::Int8, (unsigned int*)&settings->keyRelease, &keypadMenu);
   MenuEntry ky1(MENU_KP1_STR, MenuEntry::Int8, (unsigned int*)&settings->keyTouch, &keypadMenu);

   MenuEntry hystMenu(MENU_HYSTMENU_STR, MenuEntry::SubMenu, &mainMenu);
   MenuEntry hm2(MENU_HM2_STR, MenuEntry::Float, (unsigned int*)&settings->coolHyst, &hystMenu);
   MenuEntry hm1(MENU_HM1_STR, MenuEntry::Float, (unsigned int*)&settings->heatHyst, &hystMenu);

   MenuEntry sensorsMenu(MENU_SENSORSMENU_STR, MenuEntry::SubMenu, &mainMenu);
   MenuEntry sm4(MENU_SM4_STR, MenuEntry::Action, showSensors, &sensorsMenu);
   MenuEntry sm3(MENU_SM3_STR, MenuEntry::Action, discoverSensors, &sensorsMenu);
   MenuEntry sm2(MENU_SM2_STR, MenuEntry::Int8, (unsigned int*)&settings->outsideSensor,  &sensorsMenu);
   MenuEntry sm1(MENU_SM1_STR, MenuEntry::Int8, (unsigned int*)&settings->targetSensor,   &sensorsMenu);

   MenuEntry thermostatMenu(MENU_THERMOSTATMENU_STR, MenuEntry::SubMenu, &mainMenu);

   MenuEntry tms02(MENU_TMS02_STR, MenuEntry::Float, &settings->vacationTemp, &thermostatMenu);
   MenuEntry tms01(MENU_TMS01_STR, MenuEntry::UInt8, (unsigned int*)&settings->maxCycleTime, &thermostatMenu);

   MenuEntry heatingMenu(MENU_HEATINGMENU_STR, MenuEntry::SubMenu, &thermostatMenu);

   MenuEntry thm11(MENU_THM11_STR, MenuEntry::TimeMin, (unsigned int*)&settings->heatTimes[4], &heatingMenu);
   MenuEntry thm10(MENU_THM10_STR, MenuEntry::Float,   &settings->heatTemps[4], &heatingMenu);

   MenuEntry thm09(MENU_THM08_STR, MenuEntry::TimeMin, (unsigned int*)&settings->heatTimes[3], &heatingMenu);
   MenuEntry thm08(MENU_THM07_STR, MenuEntry::Float,   &settings->heatTemps[3], &heatingMenu);

   MenuEntry thm07(MENU_THM05_STR, MenuEntry::TimeMin, (unsigned int*)&settings->heatTimes[2], &heatingMenu);
   MenuEntry thm06(MENU_THM04_STR, MenuEntry::Float,   &settings->heatTemps[2], &heatingMenu);

   MenuEntry thm05(MENU_THM02_STR, MenuEntry::TimeMin, (unsigned int*)&settings->heatTimes[1], &heatingMenu);
   MenuEntry thm04(MENU_THM01_STR, MenuEntry::Float,   &settings->heatTemps[1], &heatingMenu);

   MenuEntry thm03(MENU_THM12_STR, MenuEntry::UInt8,  (unsigned int*)&settings->heatMinCycleTime, &heatingMenu);
   MenuEntry thm02(MENU_HPM4_STR,  MenuEntry::Float,  &settings->heatCycleMaximum, &heatingMenu);
   MenuEntry thm01(MENU_HPM3_STR,  MenuEntry::Float,  &settings->heatCycleMinimum, &heatingMenu);

   MenuEntry heatingPidMenu(MENU_HEATINGPIDMENU_STR, MenuEntry::SubMenu, &heatingMenu);
   MenuEntry heatingAdvancedPidMenu(MENU_HEATINGADVANCEDPIDMENU_STR, MenuEntry::SubMenu, &heatingPidMenu);

   MenuEntry hpm2(MENU_HPM2_STR,    MenuEntry::Float, &settings->heatCycleHyst, &heatingPidMenu);
   MenuEntry hpm1(MENU_HPM1_STR,    MenuEntry::YesNo, (unsigned int*)&settings->heatPidEnabled, &heatingPidMenu);
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

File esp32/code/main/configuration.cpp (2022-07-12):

#include "configuration.h"
#include "esp_log.h"
#include <iostream>
#include <map>

#include "display.h"
#include "DBGPorts.h"
#include "IOPorts.h"
#include "PID.h"
#include "PT7C4339.h"
#include "SensorData.h"

using namespace std;

#define TAG __PRETTY_FUNCTION__

static int     times[5];
static float   temps[5];

extern PID pid;
extern Configuration *config;

void show_current_sensors(std::ostream& d_out);
void showTemp(Variant& sensor, std::ostream& d_out);
void showOutsideTemp(std::ostream& d_out);
void showCycleTemp(std::ostream& d_out);
void showRoomTemp(std::ostream& d_out);
void showTargetTemp(std::ostream& d_out);
void showMode(std::ostream& d_out);
bool setMode(std::string);
void showTime(std::ostream& d_out);
bool setTime(std::string);
bool voidAction(std::string);

namespace confMenu
{
   /*************/
   /* Main Mena */
   /*************/
   MenuEntry mainMenu((const char*)"Configuration",            (const char*)"main",       MenuEntry::MainMenu);

   MenuEntry hdnEntry00((const char*)"x", (const char*)"cyc_hyst",      MenuEntry::Int,   &Configuration::m_cycleHyst,    &mainMenu, NULL, (MenuEntry::Invisible | MenuEntry::NoPermanence));
   MenuEntry hdnEntry01((const char*)"x", (const char*)"pid_enable",    MenuEntry::YesNo, &Configuration::m_pidEnabled,   &mainMenu, NULL, (MenuEntry::Invisible | MenuEntry::NoPermanence));
   MenuEntry hdnEntry02((const char*)"x", (const char*)"kp",            MenuEntry::Float, &Configuration::m_Kp,           &mainMenu, NULL, (MenuEntry::Invisible | MenuEntry::NoPermanence));
   MenuEntry hdnEntry03((const char*)"x", (const char*)"ki",            MenuEntry::Float, &Configuration::m_Ki,           &mainMenu, NULL, (MenuEntry::Invisible | MenuEntry::NoPermanence));
   MenuEntry hdnEntry04((const char*)"x", (const char*)"kd",            MenuEntry::Float, &Configuration::m_Kd,           &mainMenu, NULL, (MenuEntry::Invisible | MenuEntry::NoPermanence));
   MenuEntry hdnEntry05((const char*)"x", (const char*)"out_curve",     MenuEntry::Float, &Configuration::m_outsideCurve, &mainMenu, NULL, (MenuEntry::Invisible | MenuEntry::NoPermanence));
   MenuEntry hdnEntry06((const char*)"x", (const char*)"out_adj",       MenuEntry::Float, &Configuration::m_outsideAdj,   &mainMenu, NULL, (MenuEntry::Invisible | MenuEntry::NoPermanence));
   MenuEntry hdnEntry07((const char*)"x", (const char*)"cyc_sensor",    MenuEntry::String, &Configuration::m_cycleSensor, &mainMenu, NULL, (MenuEntry::Invisible | MenuEntry::NoPermanence));
   MenuEntry hdnEntry08((const char*)"x", (const char*)"cyc_min_time",  MenuEntry::Int,   &Configuration::m_cycleMinTime, &mainMenu, NULL, (MenuEntry::Invisible | MenuEntry::NoPermanence));
   MenuEntry hdnEntry09((const char*)"x", (const char*)"cyc_max_time",  MenuEntry::Int,   &Configuration::m_cycleMaxTime, &mainMenu, NULL, (MenuEntry::Invisible | MenuEntry::NoPermanence));
   MenuEntry hdnEntry11((const char*)"x", (const char*)"cyc_min_temp",  MenuEntry::Float, &Configuration::m_cycleMin,     &mainMenu, NULL, (MenuEntry::Invisible | MenuEntry::NoPermanence));
   MenuEntry hdnEntry12((const char*)"x", (const char*)"cyc_max_temp",  MenuEntry::Float, &Configuration::m_cycleMax,     &mainMenu, NULL, (MenuEntry::Invisible | MenuEntry::NoPermanence));
   MenuEntry hdnEntry13((const char*)"x", (const char*)"heat_override", MenuEntry::Float, &Configuration::m_heatTimes[0], &mainMenu, NULL, (MenuEntry::Invisible | MenuEntry::NoPermanence));
   MenuEntry hdnEntry14((const char*)"x", (const char*)"cool_override", MenuEntry::Float, &Configuration::m_coolTimes[0], &mainMenu, NULL, (MenuEntry::Invisible | MenuEntry::NoPermanence));
   MenuEntry hdnEntry15((const char*)"x", (const char*)"heat_temp",     MenuEntry::Float, &Configuration::m_heatTemps[0], &mainMenu, NULL, (MenuEntry::Invisible | MenuEntry::NoPermanence));
   MenuEntry hdnEntry16((const char*)"x", (const char*)"heat_time",     MenuEntry::Float, &Configuration::m_heatTimes[0], &mainMenu, NULL, (MenuEntry::Invisible | MenuEntry::NoPermanence));
   MenuEntry hdnEntry17((const char*)"x", (const char*)"cool_temp",     MenuEntry::Float, &Configuration::m_coolTemps[0], &mainMenu, NULL, (MenuEntry::Invisible | MenuEntry::NoPermanence));
   MenuEntry hdnEntry18((const char*)"x", (const char*)"cool_time",     MenuEntry::Int,   &Configuration::m_coolTimes[0], &mainMenu, NULL, (MenuEntry::Invisible | MenuEntry::NoPermanence));
   MenuEntry hdnEntry19((const char*)"x", (const char*)"vacation_mode", MenuEntry::YesNo, &Configuration::m_vacationMode, &mainMenu, NULL, (MenuEntry::Invisible | MenuEntry::NoPermanence));
   MenuEntry hdnEntry20((const char*)"x", (const char*)"ovr_offset",    MenuEntry::Float, &Configuration::m_overideOffset, &mainMenu, NULL, (MenuEntry::Invisible | MenuEntry::NoPermanence));
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

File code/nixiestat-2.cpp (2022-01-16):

# include <avr/pgmspace.h>
# include <ctype.h>
# include <math.h>
# include <stdio.h>
# include <stdlib.h>

# include "EEPROM.h"
# include "IOPort.h"

# include "datetime.h"
# include "display.h"
# include "thermostat.h"
# include "TempSensors.h"
# include "WProgram.h"
# include "Wire.h"
# include "ds1307.h"
# include "mpr121.h"
# include "switches.h"
//# include "ui.h"

# include "TemperatureLog.h"

//void printFSMSize();

// #define  DBG

#define  LOG_SIZE                (7 * 1024)
#define  READ_TEMPERATURE_TIME   20
#define  DISP_TEMPERATURE_TIME   60
#define  LOG_TEMPERATURE_TIME    280
//#define  LOG_TEMPERATURE_TIME    80

enum 
{
   TIME_LAPSE_MASK  = 0xf000,
   TIME_LAPSE_SHIFT = 12,
   CHANNEL_MASK     = 0x0c00,
   CHANNEL_SHIFT    = 10,
   TEMPERATURE_MASK = 0x03ff,
   TEMPERATURE_SIGN = 0x0200,
   LOG_LENGTH       = 12 * 1024,
   TEMP_OFFSET      = 40
};


struct eeprom 
{
   int   count;
   float minTemp;
   float maxTemp;
   int   lampOnTime;
   int   lampOffTime;
   int   compOnTime;
   int   compOffTime;
};

TemperatureLog tempLog;
TempSensors sensors;

MPR121 mpr121;

bool tempIsReady = 0;
uint8_t tempCounter = 12;

SIGNAL(TIMER1_OVF_vect)
//SIGNAL(TIMER1_COMPA_vect)
{
   uint8_t x = PINB;
   PORTB = x ^ 0x01;
   if ( ++tempCounter > 12 ) 
   {
      tempIsReady = 1;
      tempCounter = 0;
   }
}

char buf[128];
char ibuf[32];
bool needPrompt = 0;

const char invalidEntry_str[] PROGMEM = "\nInvalid Entry!";

/**********************************************************************/
/*   This  function  reads  a  floating point number from the serial  */
/*   port.  If  it's  a  valid  entry  valid  will  be  set to true,  */
/*   otherwise false.                                                 */
/*                                                                    */
/*   The function returns either the value entered or 0.0.            */
/**********************************************************************/
float getFloat(bool *valid)
{
   float rv = 0.0;
   char *cp = 0;

//   Serial << "getFloat(): enter" << endl;
   while (1) 
   {
      if ( Serial.available() )
      {
         int status = 0;
//         Serial << "here 1" << endl;
         cp = Serial.readLine(cp, &status);
         if ( status < 0 ) 
         {
            if ( valid != 0 ) 
            {
               *valid = false;
               break;
            }
         }
         else if ( status )
         {
            char *endp;
//            Serial << endl;
            if ( strlen(cp) > 0 ) 
            {
//               Serial << "have: |" << cp << "|" <<endl;
               rv = (float)strtod(cp, &endp);
//               Serial << "endp: " << (long)endp << ", cp: " << (long)cp << endl;
               if ( endp == cp ) 
                  *valid = false;
               else
                  *valid = true;
            }
            else
               *valid = false;
            break;
         }
      }
   }
   return(rv);
}

/**********************************************************************/
/*   This  function reads an integer number from the serial port. If  */
/*   it's a valid entry valid will be set to true, otherwise false.   */
/*                                                                    */
/*   The function returns either the value entered or 0.              */
/**********************************************************************/
int getInt(bool *valid)
{
   int rv = 0;
   char *cp = 0;

   while (1) 
   {
      if ( Serial.available() )
      {
         int status = 0;
         cp = Serial.readLine(cp, &status);
         if ( status < 0 ) 
         {
            if ( valid != 0 ) 
            {
               *valid = false;
               break;
            }
         }
         else if ( status )
         {
            char *endp;
//            Serial << endl;
            if ( strlen(cp) > 0 ) 
            {
//               Serial << "have: |" << cp << "|" <<endl;
               rv = (int)strtol(cp, &endp, 10);
//               Serial << "rv: << " << rv << ", endp: " << (long)endp << ", cp: " << (long)cp << endl;
               if ( endp == cp ) 
                  *valid = false;
               else
                  *valid = true;
            }
            else
               *valid = false;
            break;
         }
      }
   }
   return(rv);
}

void writeEEProm()
{
   struct eeprom ee;
   
   byte *cp = (byte*)&ee;
   for (int x = 0; x < sizeof(ee); x++)
      *(cp++) = EEPROM.read(x);
   if ( ee.count >= 0  ) 
      ee.count++;
   else
      ee.count = 1;

/*
   ee.minTemp     = minTemp;
   ee.maxTemp     = maxTemp;
   ee.lampOnTime  = lampOnTime;
   ee.lampOffTime = lampOffTime;
   ee.compOnTime  = compOnTime;
   ee.compOffTime = compOffTime;
*/
   cp = (byte*)&ee;
   for (int x = 0; x < sizeof(ee); x++)
      EEPROM.write(x, *(cp++));
}

void readEEProm()
{
   struct eeprom ee;
   byte *cp = (byte*)&ee;
   for (int x = 0; x < sizeof(ee); x++)
      *(cp++) = EEPROM.read(x);
/*
   if ( ee.count == -1 )
   {
      minTemp     = 33.0;
      maxTemp     = 34.0;
      lampOnTime  = 1 * 60;
      lampOffTime = 3 * 60;
      compOnTime  = 15;
      compOffTime = 15;
   }
   else 
   {
      minTemp     = ee.minTemp;
      maxTemp     = ee.maxTemp;
      lampOnTime  = ee.lampOnTime;
      lampOffTime = ee.lampOffTime;
      compOnTime  = ee.compOnTime;
      compOffTime = ee.compOffTime;
   }
*/
}
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

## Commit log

2022-01-16 Initial import of //depot/nixiestat/ from the state at revision #head
    [git-p4: depot-paths = "//depot/nixiestat/": change = 313]
    [configuration.h, cpu-board.kicad_pcb, cpu-board.sch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]
2022-01-16 Initial revision for the display pcb and schematic
    [git-p4: depot-paths = "//depot/nixiestat/": change = 315]
    [nixie-display.kicad_pcb, nixie-display.sch, nixie_display_io.sch]
2022-01-16 Added ground connection, broke the schematic into two sheets
    [git-p4: depot-paths = "//depot/nixiestat/": change = 316]
    [IODrivers.sch, cpu-board.kicad_pcb, cpu-board.sch]
2022-01-31 Fixed IN-17 foot prints, Anode drivers, little stuff
    [git-p4: depot-paths = "//depot/nixiestat/": change = 320]
    [anode_drivers.sch, nixie-display.kicad_pcb, nixie-display.sch]
2022-02-04 Modified to to use simplified keys through the json interface Modified to provide feedback on invalid keys Added seperate json discovery commands show_keys, known_sensors
    [git-p4: depot-paths = "//depot/nixiestat/": change = 323]
    [configuration.h]
2022-02-25 First attempt at ensuring proper grounding Added capacitor to the reset pin Extended the reset line to the IO extenders
    [git-p4: depot-paths = "//depot/nixiestat/": change = 324]
    [IODrivers.sch, cpu-board.kicad_pcb, cpu-board.sch]
2022-02-25 Moved the text on the bottom silkscreen to the bottom copper
    [git-p4: depot-paths = "//depot/nixiestat/": change = 325]
    [cpu-board.kicad_pcb]
2022-02-25 Just a small fix
    [git-p4: depot-paths = "//depot/nixiestat/": change = 327]
    [cpu-board.kicad_pcb]
2022-02-25 Improved grounding New Anode Drivers
    [git-p4: depot-paths = "//depot/nixiestat/": change = 328]
    [anode_drivers.sch, nixie-display.kicad_pcb, nixie-display.sch]
2022-02-25 Small change
    [git-p4: depot-paths = "//depot/nixiestat/": change = 329]
    [nixie-display.kicad_pcb]
2022-02-27 Finishing touches on the board clean up (until the next round)
    [git-p4: depot-paths = "//depot/nixiestat/": change = 330]
    [configuration.h, cpu-board.kicad_pcb, nixie-display.kicad_pcb]
2022-02-27 Design Rule cleanup
    [git-p4: depot-paths = "//depot/nixiestat/": change = 331]
    [nixie-display.kicad_pcb]
2022-02-28 Further ground work
    [git-p4: depot-paths = "//depot/nixiestat/": change = 332]
    [cpu-board.kicad_pcb]
2022-02-28 Further ground work
    [git-p4: depot-paths = "//depot/nixiestat/": change = 333]
    [nixie-display.kicad_pcb]
2022-03-02 Fixed SensorData::isValid, Added multi-sensor target support
    [git-p4: depot-paths = "//depot/nixiestat/": change = 334]
2022-03-17 Added RTC
    [git-p4: depot-paths = "//depot/nixiestat/": change = 335]
    [cpu-board.kicad_pcb, cpu-board.sch]
2022-03-31 Changed RTOS tick to 1ms, restructured wifi processing, added display and keyboard handling, integrated PT7C4339 RTC into the code
    [git-p4: depot-paths = "//depot/nixiestat/": change = 336]
    [configuration.h]
2022-05-29 New Zen design
    [git-p4: depot-paths = "//depot/nixiestat/": change = 356]
    [anode_drivers.sch, nixie-display.kicad_pcb, nixie-display.sch]
2022-05-29 Added new 4 key touch pad board
    [git-p4: depot-paths = "//depot/nixiestat/": change = 357]
    [touch-panel2.kicad_pcb, touch-panel2.sch]
2022-05-29 Fixed keywords for PCB
    [git-p4: depot-paths = "//depot/nixiestat/": change = 358]
    [dev-board.kicad_pcb, dev-board.sch, touch-panel2.kicad_pcb]
2022-05-29 Fixed copper zone
    [git-p4: depot-paths = "//depot/nixiestat/": change = 359]
    [touch-panel2.kicad_pcb]
2022-05-29 Updated dates and such
    [git-p4: depot-paths = "//depot/nixiestat/": change = 360]
    [anode_drivers.sch, nixie-display.kicad_pcb, nixie-display.sch]

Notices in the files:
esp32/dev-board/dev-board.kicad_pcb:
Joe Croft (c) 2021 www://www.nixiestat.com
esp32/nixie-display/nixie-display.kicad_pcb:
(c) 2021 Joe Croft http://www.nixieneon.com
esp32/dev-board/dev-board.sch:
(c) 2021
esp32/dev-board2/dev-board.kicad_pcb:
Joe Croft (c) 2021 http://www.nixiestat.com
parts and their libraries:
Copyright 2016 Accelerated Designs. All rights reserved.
